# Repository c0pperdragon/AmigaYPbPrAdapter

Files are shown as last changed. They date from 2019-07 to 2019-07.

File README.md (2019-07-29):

# Amiga YPbPr Adapter

To get the best possible image quality from a vintage Amiga (specifically Amiga 500) home computer.

The Amiga basically supports RGB output natively, but this standard is not suitable to directly
feed into a modern mid-range TV. The way to go with current TVs is component video (a.k.a YPbPr) that
has basically the same quality as RGB but uses a different way to encode everything.

As a matter of fact, the Y of YPbPr is just the (monochrome) luma signal together with sync, which is 
identical to the signal many Amiga computers (the 1000, 500, 2000 and maybe others as well) already provide 
on their composite output port. 
So it is only necessary to create the suitable Pb and Pr signals to get full-blown YPbPr.

The adapter is intended to plug into the RGB video connector to produce the two missing signals.
Unluckily the RGB connector of the Amiga requires a female 23-pin SUB-D plug, and these connectors
are no longer in production. A 25-pin connector can be trimmed down to somehow fit, but this
requires quite some manual work and mass-production is out of the question. 

Nevertheless, I make everything open source in case someone else wants to build it. It is especially designed
for home-etching so it uses only a single-sided board with some jumper wires on the other side. 
The only non-trivial components are the 3 op-amp packages (with 2 op-amps each). These must be some standard
high-speed parts in SOIC-8 packages. Rail-to-rail operation with 5 volt supply is preferable, but it should
also work with other parts as well. 
 
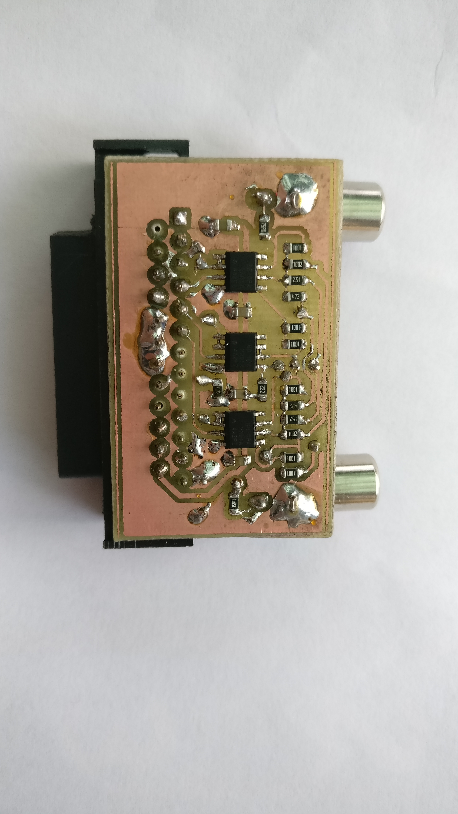
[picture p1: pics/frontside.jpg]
Adapter front side

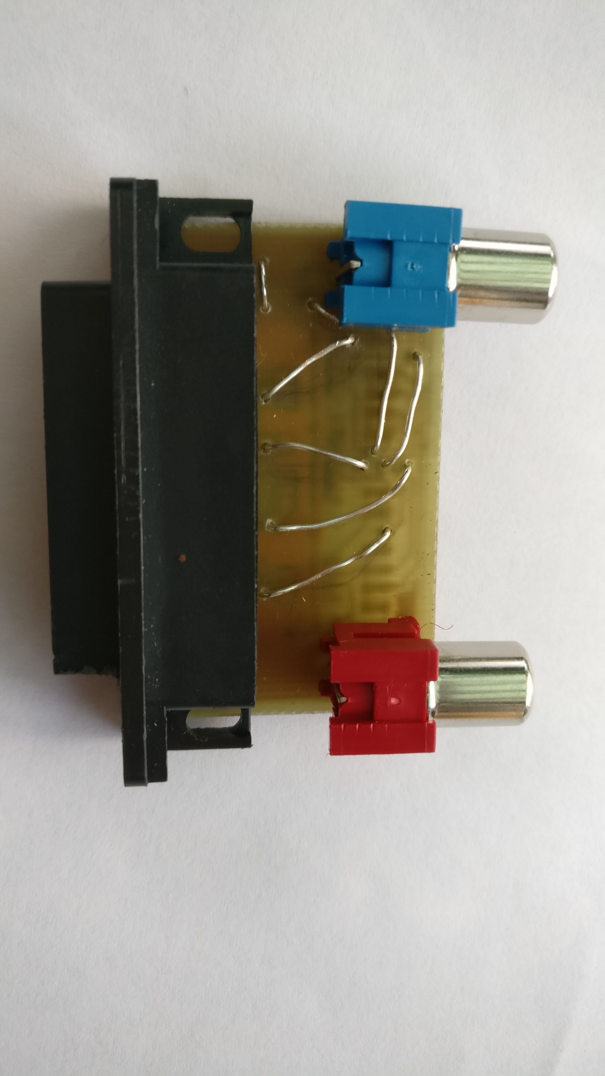
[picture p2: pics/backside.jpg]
Adapter back side


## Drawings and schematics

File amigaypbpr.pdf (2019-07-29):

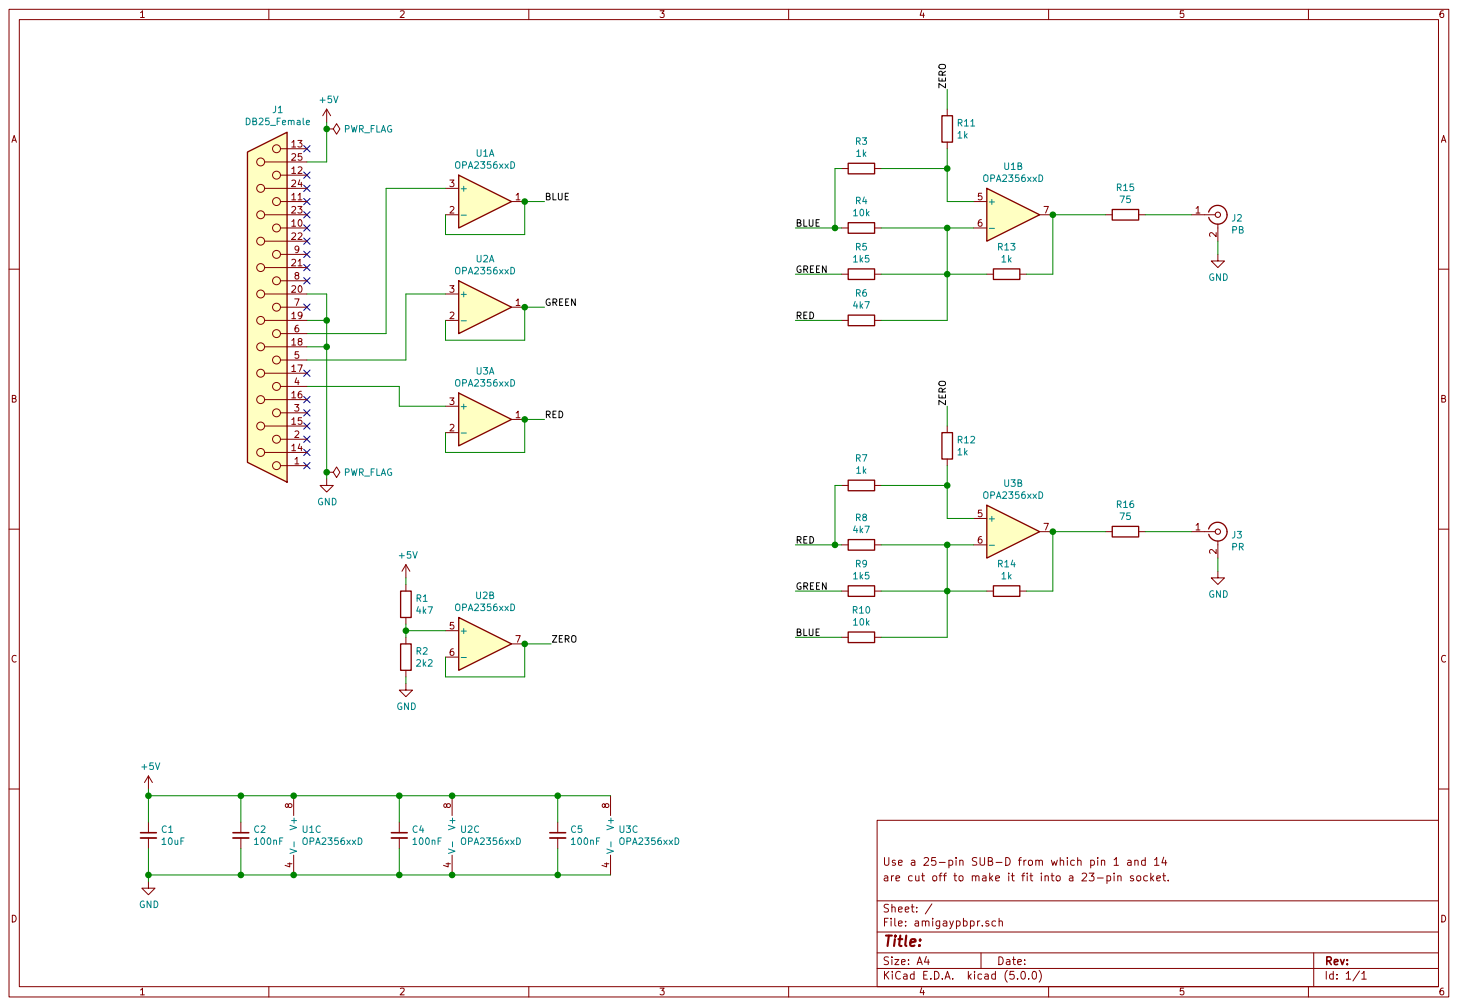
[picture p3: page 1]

Use a 25-pin SUB-D from which pin 1 and 14 RED GREEN

File: amigaypbpr.sch Sheet: / are cut off to make it fit into a 23-pin socket.

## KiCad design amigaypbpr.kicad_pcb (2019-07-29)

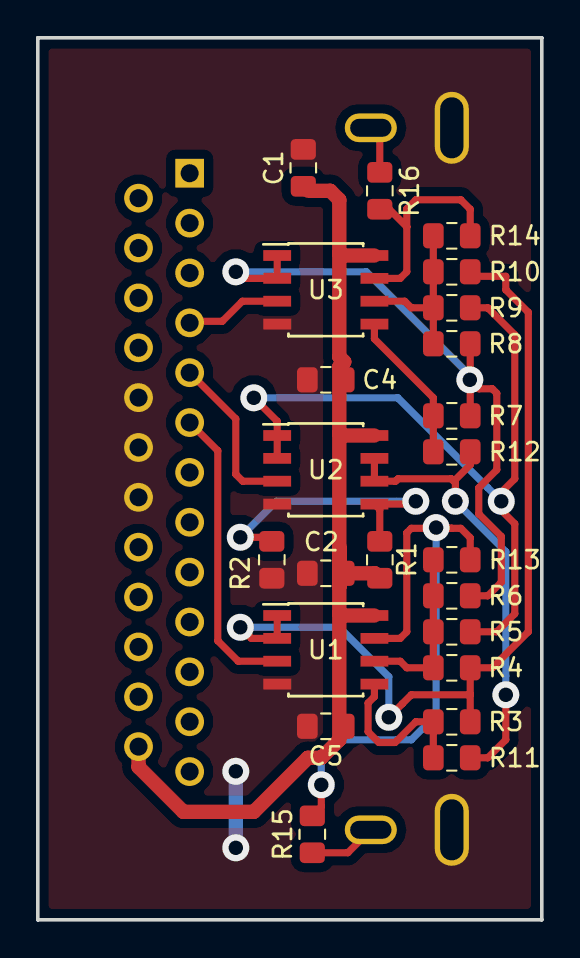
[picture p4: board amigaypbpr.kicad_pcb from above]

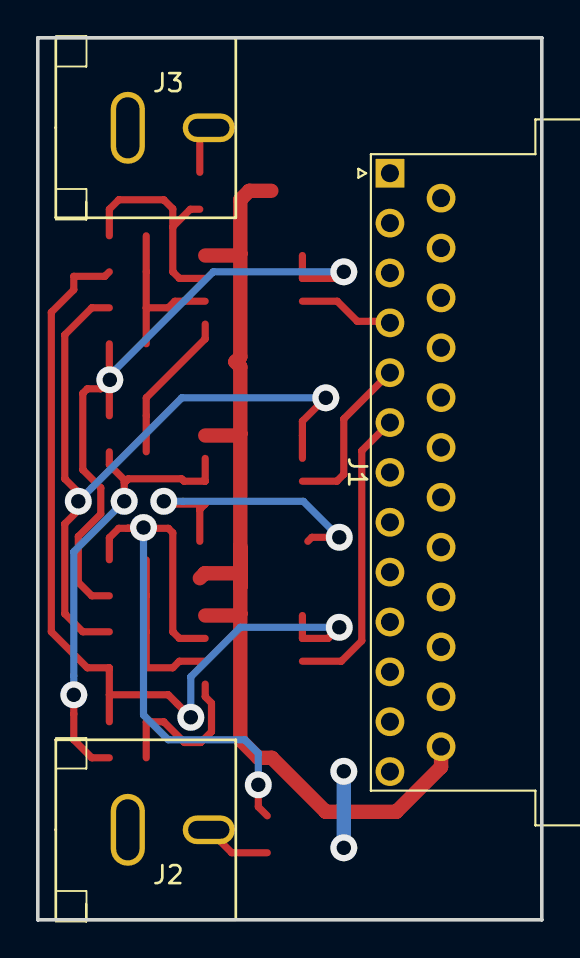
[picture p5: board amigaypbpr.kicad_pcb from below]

Board: 2 copper layers, 28.0 x 49.0 mm, 26 parts (3 on the bottom side), 18 nets.

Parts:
C1: 10uF; C_0805_2012Metric_Pad1.15x1.40mm_HandSolder
C2, C4, C5: 100nF; C_0805_2012Metric_Pad1.15x1.40mm_HandSolder
J1: DB25_Female; DSUB-25_Female_Horizontal_P2.77x2.84mm_EdgePinOffset9.40mm
J2: PB; RCA_JACK
J3: PR; RCA_JACK
R1, R6, R8: 4k7; R_0805_2012Metric_Pad1.15x1.40mm_HandSolder
R2: 2k2; R_0805_2012Metric_Pad1.15x1.40mm_HandSolder
R3, R7, R11, R12, R13, R14: 1k; R_0805_2012Metric_Pad1.15x1.40mm_HandSolder
R4, R10: 10k; R_0805_2012Metric_Pad1.15x1.40mm_HandSolder
R5, R9: 1k5; R_0805_2012Metric_Pad1.15x1.40mm_HandSolder
R15, R16: 75; R_0805_2012Metric_Pad1.15x1.40mm_HandSolder
U1, U2, U3: OPA2356xxD; SOIC-8_3.9x4.9mm_P1.27mm

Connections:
+5V: C1.1, C2.1, C4.1, C5.1, J1.25, R1.1, U1.8, U2.8, U3.8
/BLUE: R3.2, R4.2, R10.2, U1.1, U1.2
/GREEN: R5.2, R9.2, U2.1, U2.2
/RED: R6.2, R7.2, R8.2, U3.1, U3.2
/ZERO: R11.1, R12.1, U2.6, U2.7
GND: C1.2, C2.2, C4.2, C5.2, J1.18, J1.19, J1.20, J2.2, J3.2, R2.2, U1.4, U2.4, U3.4
unnamed: J1.4, U3.3
unnamed: J1.5, U2.3
unnamed: J1.6, U1.3
unnamed: J2.1, R15.1
unnamed: J3.1, R16.1
unnamed: R1.2, R2.1, U2.5
unnamed: R8.1, R9.1, R10.1, R14.2, U3.6
unnamed: R3.1, R11.2, U1.5
unnamed: R7.1, R12.2, U3.5
unnamed: R13.1, R15.2, U1.7
unnamed: R4.1, R5.1, R6.1, R13.2, U1.6
unnamed: R14.1, R16.2, U3.7

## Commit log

2019-07-25 Board design and layout
    [amigaypbpr.kicad_pcb, amigaypbpr.sch]
2019-07-29 More documentation and pictures
    [amigaypbpr.kicad_pcb]
